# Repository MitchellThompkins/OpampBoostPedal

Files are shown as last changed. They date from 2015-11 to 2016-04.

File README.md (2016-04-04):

## Description

This is a low-cost op-amp boost pedal meant for use with guitar. The form factor is intended to be very small. Included you will find the eagle files for the board, wiring diagrams, finished photos, pspice simulation files, and a bill of materials to estimate the total cost. PSpice simulations are also included.

### Current revision of the PCB:

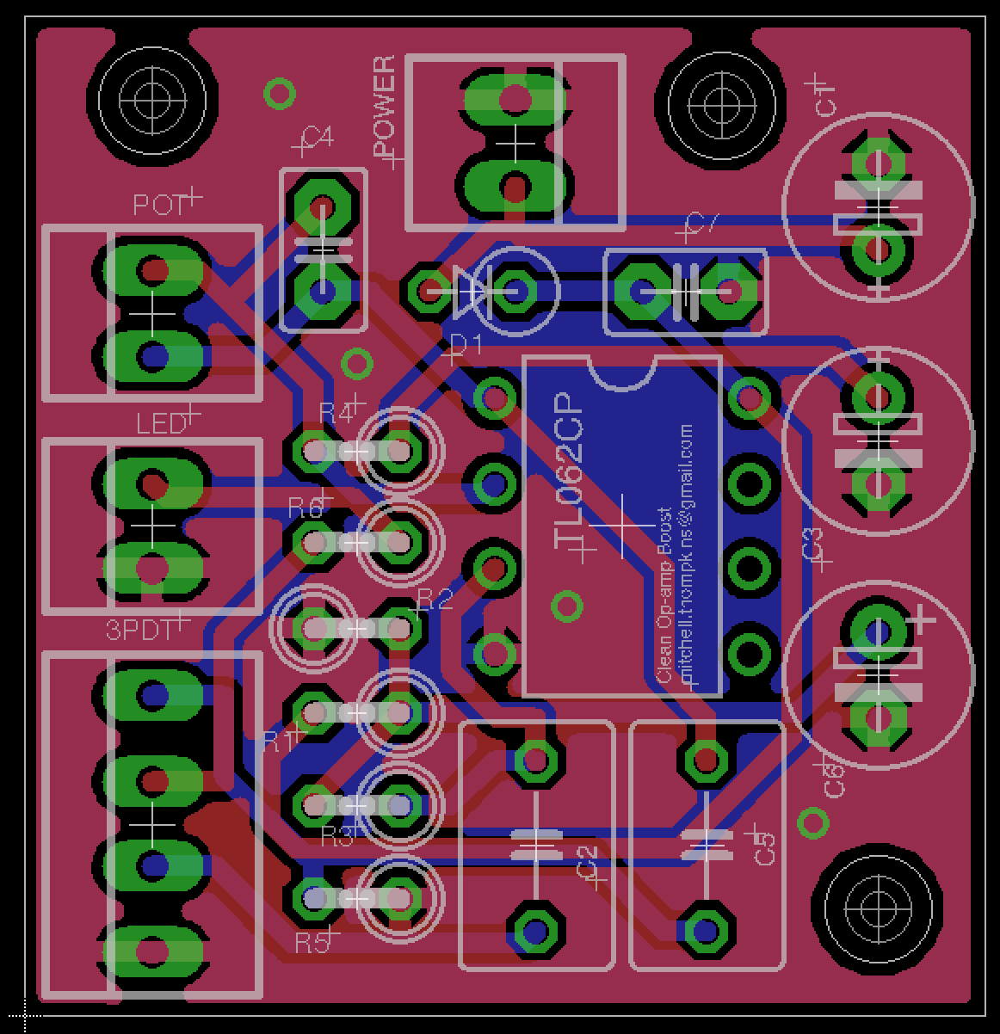
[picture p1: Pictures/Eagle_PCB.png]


### The populated board:

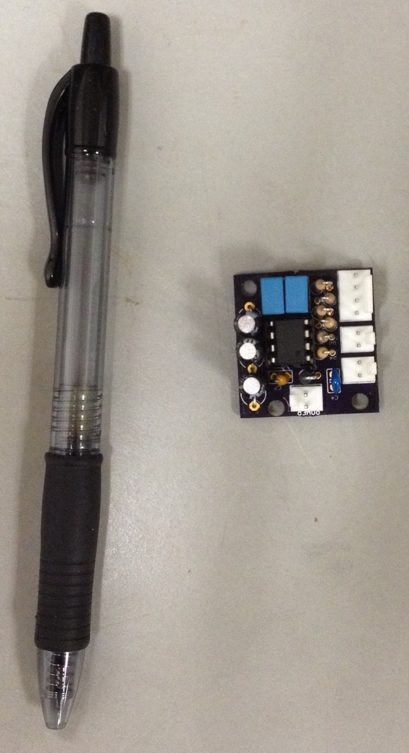
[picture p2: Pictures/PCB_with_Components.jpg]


### Finished Pedal:

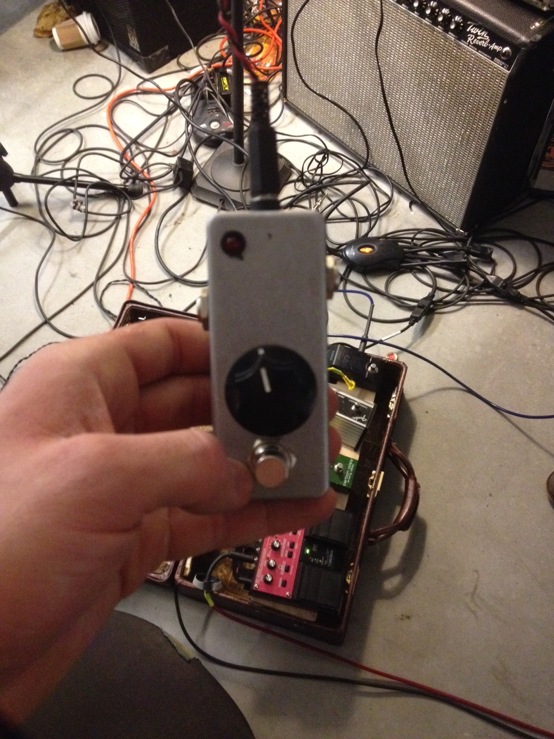
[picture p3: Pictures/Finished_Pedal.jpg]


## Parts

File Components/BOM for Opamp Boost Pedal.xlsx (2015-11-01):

Part | Vendor | Cost | Quantity | Total Cost
WITHOUT MOLEX CONNECTORS
3PDT Footswitch Latched - Solder Lugs - BLUE (http://www.bitcheslovemyswitches.com/#!/~/product/category=5027572&id=10054083) | Bitches Love My Switches | $2.22 | 1 | $2.22
Enclosure 1590A (http://www.bitcheslovemyswitches.com/#!/~/product/category=5027533&id=21743333) | Bitches Love My Switches | $3.50 | 1 | $3.50
1/4 Black Chicken Head Knob (http://www.bitcheslovemyswitches.com/#!/~/category/id=5223977&offset=0&sort=normal) | Bitches Love My Switches | $0.80 | 1 | $0.80
1/4 Mono Open Jack - Neutrik NYS229 (http://www.bitcheslovemyswitches.com/#!/~/product/category=5027593&id=18726663) | Bitches Love My Switches | $0.99 | 2 | $1.98
Thinline 2.1mm DC Power Jack (http://www.bitcheslovemyswitches.com/#!/~/product/category=5027592&id=18921807) | Bitches Love My Switches | $0.63 | 1 | $0.63
Alpha Single-Gang Audio Taper 50k (http://www.pedalpartsplus.com/mm5/merchant.mvc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) | Pedal Parts Plus | $1.09 | 1 | $1.09
CAP ALUM 1UF 50V 20% RADIAL (http://www.digikey.com/product-detail/en/UVK1H010MDD1TD/493-12567-1-ND/4328648) | Digi-Key | $0.14 | 1 | $0.14
CAP ALUM 10UF 35V 20% RADIAL (http://www.digikey.com/product-detail/en/ESK106M035AC3AA/399-6598-ND/3083013) | Digi-Key | $0.15 | 2 | $0.30
CAP CER 0.1UF 50V 20% RADIAL (http://www.digikey.com/product-detail/en/SR295E104MAR/478-5741-ND/2136301) | Digi-Key | $0.24 | 1 | $0.24
CAP FILM 1UF 63VDC RADIAL (http://www.digikey.com/product-detail/en/B32529C105J/495-1119-ND/592697) | Digi-Key | $0.62 | 2 | $1.24
CAP CER 47PF 50V 5% RADIAL (http://www.digikey.com/product-search/en?WT.z_header=search_go&lang=en&site=us&x=0&y=0&formaction=on) | Digi-Key | $0.29 | 1 | $0.29
IC OPAMP JFET 1MHZ 8DIP (http://www.digikey.com/product-detail/en/TL062CP/296-1771-5-ND/277417) | Digi-Key | $0.70 | 1 | $0.70
RES 2.7K OHM 1/4W 5% CF AXIAL (http://www.digikey.com/product-detail/en/CF14JT2K70/CF14JT2K70CT-ND/1830360) | Digi-Key | $0.08 | 1 | $0.08
RES 100K OHM 1/4W 5% CARBON FILM (http://www.digikey.com/product-detail/en/CF14JT100K/CF14JT100KCT-ND/1830399) | Digi-Key | $0.08 | 3 | $0.24
RES 560 OHM 1/4W 5% AXIAL (http://www.digikey.com/product-detail/en/CFR-25JB-52-560R/560QBK-ND/2464) | Digi-Key | $0.10 | 1 | $0.10
RES 10M OHM 1/4W 5% CARBON FILM (http://www.digikey.com/product-detail/en/CF14JT10M0/CF14JT10M0CT-ND/1830444) | Digi-Key | $0.08 | 2 | $0.16
DIODE GEN PURPOSE 400V 1A DO41 (http://www.digikey.com/product-detail/en/1N4004-TP/1N4004-TPMSCT-ND/773691) | Digi-Key | $0.11 | 1 | $0.11
Boost Pedal PCB (http://oshpark.com/profiles/a_soy_milkshake) | OshPark | $2.20 | 3 | $6.60
 |  |  | Total | 20.42
WITH MOLEX CONNECTORS
3PDT Footswitch Latched - Solder Lugs - BLUE (http://www.bitcheslovemyswitches.com/#!/~/product/category=5027572&id=10054083) | Bitches Love My Switches | $2.22 | 1 | $2.22
Enclosure 1590A (http://www.bitcheslovemyswitches.com/#!/~/product/category=5027533&id=21743333) | Bitches Love My Switches | $3.50 | 1 | $3.50
1/4 Black Chicken Head Knob (http://www.bitcheslovemyswitches.com/#!/~/category/id=5223977&offset=0&sort=normal) | Bitches Love My Switches | $0.80 | 1 | $0.80
1/4 Mono Open Jack - Neutrik NYS229 (http://www.bitcheslovemyswitches.com/#!/~/product/category=5027593&id=18726663) | Bitches Love My Switches | $0.99 | 2 | $1.98
Thinline 2.1mm DC Power Jack (http://www.bitcheslovemyswitches.com/#!/~/product/category=5027592&id=18921807) | Bitches Love My Switches | $0.63 | 1 | $0.63
Alpha Single-Gang Audio Taper 50k (http://www.pedalpartsplus.com/mm5/merchant.mvc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) | Pedal Parts Plus | $1.09 | 1 | $1.09
CONN HEADER 2POS .100 VERT TIN (http://www.digikey.com/product-search/en?WT.z_header=search_go&lang=en&site=us&x=0&y=0&formaction=on) | Digi-Key | $0.20 | 3 | $0.60
CONN HEADER 4POS .100 VERT TIN (http://www.digikey.com/product-search/en?vendor=0&keywords=WM4202-ND) | Digi-Key | $0.37 | 1 | $0.37
CONN HSNG 2POS .100 W/RAMP/RIB (http://www.digikey.com/product-detail/en/0022012025/WM2613-ND/1634858) | Digi-Key | $0.29 | 3 | $0.87
CONN HSNG 4POS .100 W/RAMP/RIB (http://www.digikey.com/product-search/en?vendor=0&keywords=CONN+HSNG+4POS+.100+W%2FRAMP%2FRIB) | Digi-Key | $0.40 | 1 | $0.40
CONN TERM CRIMP 22-30AWG TIN (http://www.digikey.com/product-detail/en/0008500135/WM9727CT-ND/4037903) | Digi-Key | $0.10 | 12 | $1.20
CAP ALUM 1UF 50V 20% RADIAL (http://www.digikey.com/product-detail/en/UVK1H010MDD1TD/493-12567-1-ND/4328648) | Digi-Key | $0.14 | 1 | $0.14
CAP ALUM 10UF 35V 20% RADIAL (http://www.digikey.com/product-detail/en/ESK106M035AC3AA/399-6598-ND/3083013) | Digi-Key | $0.15 | 2 | $0.30
CAP CER 0.1UF 50V 20% RADIAL (http://www.digikey.com/product-detail/en/SR295E104MAR/478-5741-ND/2136301) | Digi-Key | $0.24 | 1 | $0.24
CAP FILM 1UF 63VDC RADIAL (http://www.digikey.com/product-detail/en/B32529C105J/495-1119-ND/592697) | Digi-Key | $0.62 | 2 | $1.24
CAP CER 47PF 50V 5% RADIAL (http://www.digikey.com/product-search/en?WT.z_header=search_go&lang=en&site=us&x=0&y=0&formaction=on) | Digi-Key | $0.29 | 1 | $0.29
IC OPAMP JFET 1MHZ 8DIP (http://www.digikey.com/product-detail/en/TL062CP/296-1771-5-ND/277417) | Digi-Key | $0.70 | 1 | $0.70
RES 2.7K OHM 1/4W 5% CF AXIAL (http://www.digikey.com/product-detail/en/CF14JT2K70/CF14JT2K70CT-ND/1830360) | Digi-Key | $0.08 | 1 | $0.08
RES 100K OHM 1/4W 5% CARBON FILM (http://www.digikey.com/product-detail/en/CF14JT100K/CF14JT100KCT-ND/1830399) | Digi-Key | $0.08 | 3 | $0.24
RES 560 OHM 1/4W 5% AXIAL (http://www.digikey.com/product-detail/en/CFR-25JB-52-560R/560QBK-ND/2464) | Digi-Key | $0.10 | 1 | $0.10
RES 10M OHM 1/4W 5% CARBON FILM (http://www.digikey.com/product-detail/en/CF14JT10M0/CF14JT10M0CT-ND/1830444) | Digi-Key | $0.08 | 2 | $0.16
DIODE GEN PURPOSE 400V 1A DO41 (http://www.digikey.com/product-detail/en/1N4004-TP/1N4004-TPMSCT-ND/773691) | Digi-Key | $0.11 | 1 | $0.11
Boost Pedal PCB (http://oshpark.com/profiles/a_soy_milkshake) | OshPark | $2.20 | 3 | $6.60
 |  |  | Total | 23.86

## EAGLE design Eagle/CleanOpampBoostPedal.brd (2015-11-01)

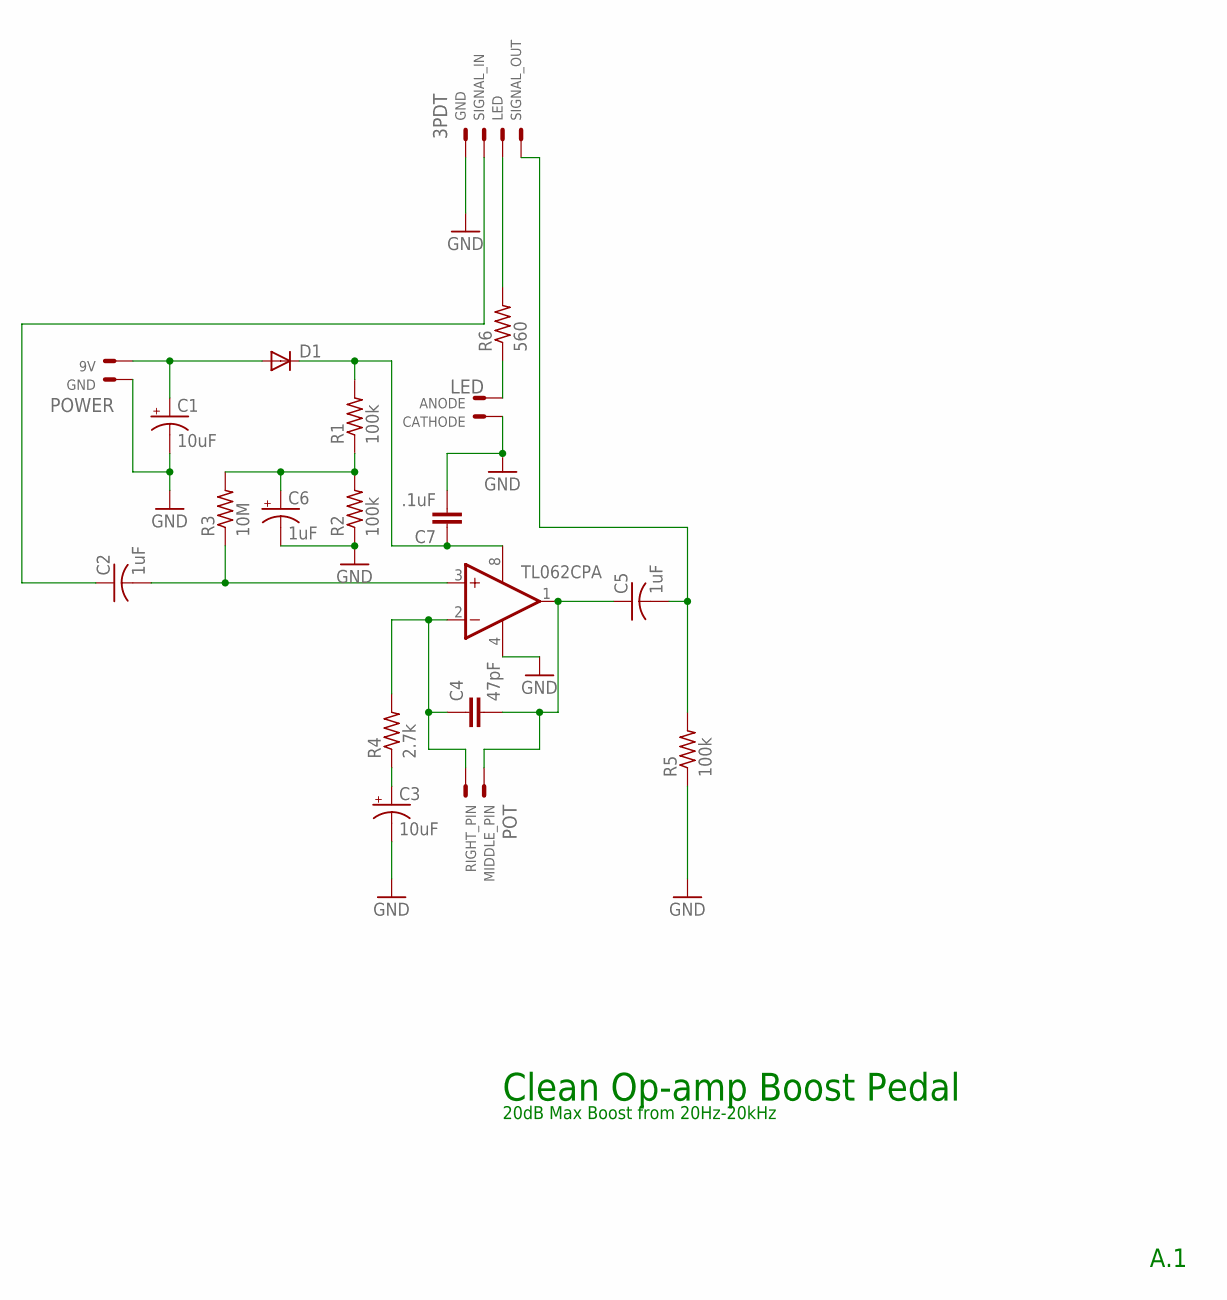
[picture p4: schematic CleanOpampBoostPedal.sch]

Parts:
3PDT: 22-23-2041
C1, C3: 10uF; E2,5-6E
C2, C5: 1uF; C050-045X075
C4: 47pF; C2.5-2
C6: 1uF; E2,5-6
C7: .1uF; C2.5-2
D1: DIODE-D-2.5; D-2.5
LED: 22-23-2021
POT: 22-23-2021
POWER: 22-23-2021
R1, R2, R5: 100k; 0207/2V
R3: 10M; 0207/2V
R4: 2.7k; 0207/2V
R6: 560; 0207/2V
TL062CP: LM1458N; DIL08

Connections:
GND: 3PDT.1, C1.-, C3.-, C6.-, C7.2, LED.1, POWER.1, R2.1, R5.1, TL062CP.4 (V-)
unnamed: C2.2, R3.1, TL062CP.3 (+IN)
unnamed: 3PDT.3, R6.2
unnamed: C7.1, D1.C, R1.2, TL062CP.8 (V+)
unnamed: C1.+, D1.A, POWER.2
unnamed: LED.2, R6.1
unnamed: C3.+, R4.1
unnamed: C4.1, POT.2, R4.2, TL062CP.2 (-IN)
unnamed: C4.2, C5.1, POT.1, TL062CP.1 (OUT)
unnamed: 3PDT.4, C5.2, R5.2
unnamed: 3PDT.2, C2.1
unnamed: C6.+, R1.1, R2.2, R3.2

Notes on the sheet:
20dB Max Boost from 20Hz-20kHz
Clean Op-amp Boost Pedal
A.1

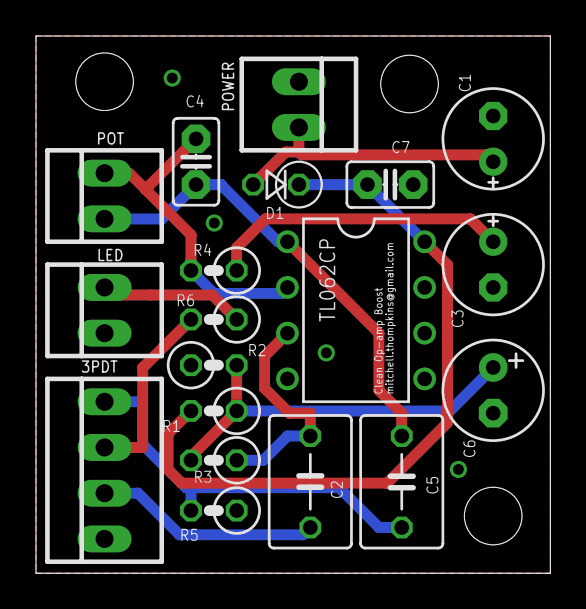
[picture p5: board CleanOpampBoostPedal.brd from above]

Board: 2 copper layers, 28.6 x 29.8 mm, 19 parts (0 on the bottom side), 12 nets.

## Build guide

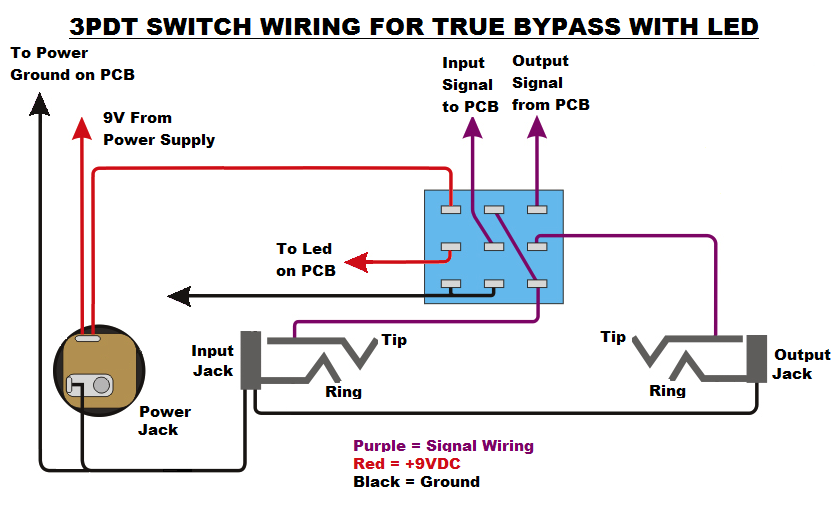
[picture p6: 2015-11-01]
Pictures/3PDT_Wiring.png

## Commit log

2015-11-01 Added Readme. Removed OS files.
    [Opamp Boost Pedal.brd, Opamp Boost Pedal.sch]
2015-11-01 Added Readme. Fixed OS files.
    [CleanOpampBoostPedal.brd, CleanOpampBoostPedal.sch]

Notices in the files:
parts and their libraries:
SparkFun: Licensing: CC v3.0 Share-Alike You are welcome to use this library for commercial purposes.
